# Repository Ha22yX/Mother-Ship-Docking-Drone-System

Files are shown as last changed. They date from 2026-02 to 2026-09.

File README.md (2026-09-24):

<div align="center">
  <h1>Mother-Ship Docking Drone System</h1>
  <p>My project exploring how GPS, UWB, and vision can work together for relative positioning and drone docking.</p>

  <p>
    <a href="README.zh-CN.md">Chinese</a>
    &middot;
    <a href="https://isef.rosebeg.com">Project Website</a>
    &middot;
    <a href="https://github.com/Ha22yX/UWB-Project">UWB Module</a>
    &middot;
    <a href="https://github.com/Ha22yX/OpenMV-AprilTag">Vision Module</a>
  </p>

  <p>
    
    
    
    
    
  </p>
</div>

<p align="center">
  Mother-Ship Docking Drone System overview: GPS, UWB, and vision for mother-frame relative positioning
</p>

I am building a system that would let a smaller drone approach and dock with a larger “mother” drone in the air. This repository records my hardware, code, and experiments as I work toward that goal.

**Current status:** I have completed the theoretical work and validation of the underlying principles. I have assembled the hardware and carried out preliminary flight tests, including a test with the two drones connected before takeoff. The complete autonomous approach and docking sequence is still unfinished.

## Why I started this project

I have thought drones were cool since I was a kid. I wanted to turn that interest into something I could design, build, and test myself, and getting two drones to meet and dock in the air gave me a problem I wanted to work on.

The question that drew me in was how to get an accurate relative position estimate over a wide range of distances. For the docking system I want to build, relying on a single sensing method makes it difficult to balance coverage, precision, and reliability.

GPS offers wide outdoor coverage, but ordinary GPS alone does not provide the precision I need for close docking. [RTK can improve GNSS accuracy](https://www.u-blox.com/en/technologies/rtk-real-time-kinematic) with correction data and suitable signal conditions. UWB and AprilTag vision can provide more precise local measurements for this task, but UWB needs the drone to stay within the anchors' useful range, and the camera needs a clear view of the marker at a usable distance.

That is why I want to combine these methods: satellite positioning for the wider approach, UWB for relative positioning as the drones get closer, and vision for the final alignment. My goal is to explore how sensor fusion can keep the relative position estimate useful across those stages, using drone docking as the application. It connects a positioning problem I want to solve with something I have enjoyed since childhood.

## What I am trying to build

I wanted to explore how one drone could find another and line up with it while both are moving. For docking, the smaller drone needs to know its position relative to the mother drone's frame, including how far it is from the docking point.

My design uses different sensors at different stages:

| Stage | Method | What I use it for |
| --- | --- | --- |
| Initial approach | GPS / RTK-GPS | Bring the drones into the same area. |
| Relative positioning | UWB anchors on the mother frame and a tag on the child drone | Calculate the child drone's position relative to the docking frame. |
| Close-range alignment | OpenMV camera and AprilTag markers | Estimate the remaining position and angle offset. |
| Connection | PX4 / MAVLink and an electromagnetic docking mechanism | Control the final approach and connect the two drones. |

The UWB part turns distances from several anchors into a local `x, y, z` estimate. The camera is intended to refine the alignment close to the docking point. The complete sequence still needs to be validated in flight.

## Building the hardware

I designed parts in SolidWorks and assembled physical prototypes for testing. The [CAD files](hardware/solidworks/) include the drone platform, docking frame, battery bay, GPS mounts, clamps, and electromagnet connectors.

The photo below shows the larger test setup with the mother frame and child drone.

<p align="center">
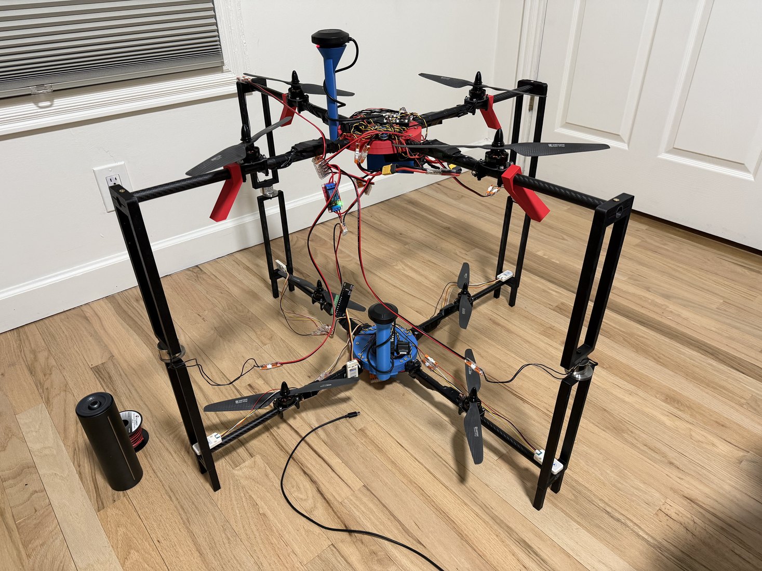
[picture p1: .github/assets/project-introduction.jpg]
Mother-frame docking structure and child drone in the assembled test setup
  
</p>

These two photos show my assembly work in more detail:

<table>
  <tr>
    <td align="center" width="50%">
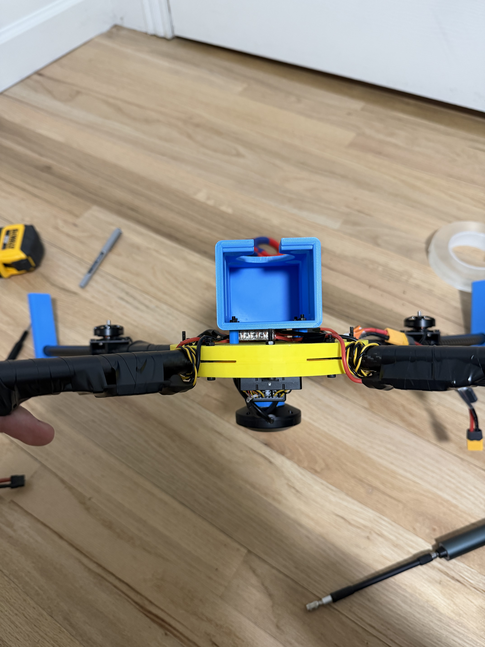
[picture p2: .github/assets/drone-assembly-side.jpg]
Side view of my drone assembly, showing the central frame, blue mount, wiring, and components underneath
      
    </td>
    <td align="center" width="50%">
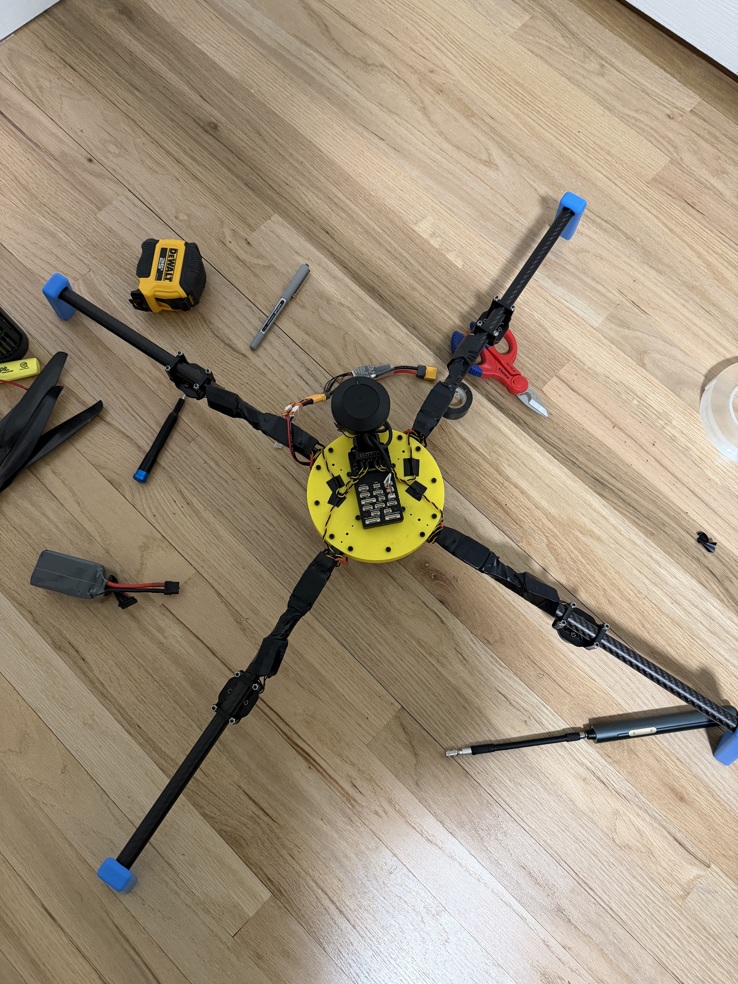
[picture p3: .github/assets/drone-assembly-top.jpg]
Top view of my drone assembly, showing the arms, motors, central plate, and electronics
      
    </td>
  </tr>
  <tr>
    <td align="center">Side view during assembly.</td>
    <td align="center">Top view of the frame and electronics during assembly.</td>
  </tr>
</table>

## Testing the two drones while connected

Before attempting docking between independently flying drones, I connected the two drones on the ground and tested them together. I wanted to check whether they could take off and fly safely in that connected configuration.

<p align="center">
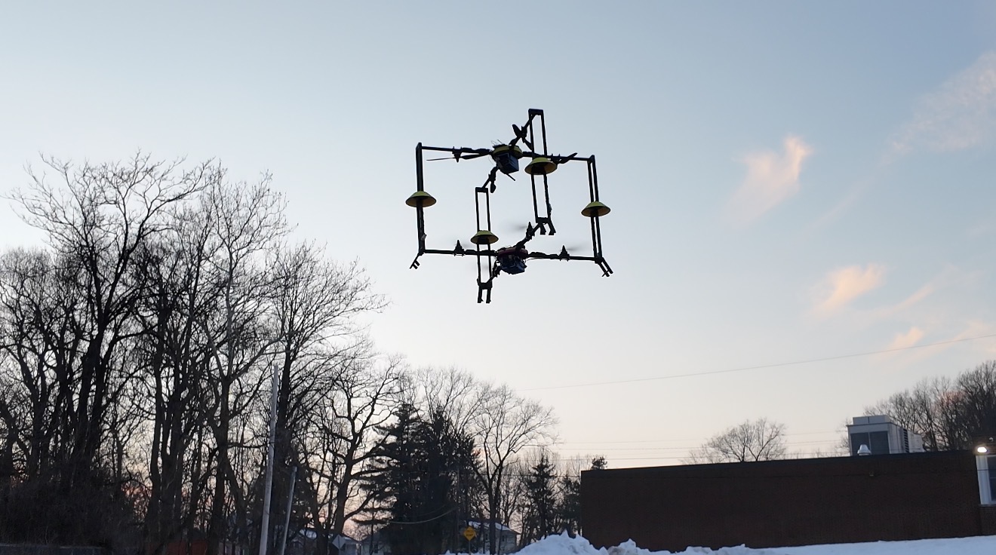
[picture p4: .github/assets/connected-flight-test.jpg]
The two drones airborne during a preliminary test with them already connected before takeoff
  
</p>

*The two drones during a flight test with them already connected before takeoff.*

This photo records a preliminary test of flying together. Autonomous approach, alignment, and connection in the air still need their own complete validation.

## Where I am now

| Part of the project | Progress |
| --- | --- |
| Theoretical design and validation of the underlying principles | Completed. |
| Hardware design and assembly | Physical prototypes built; CAD files and assembly photos included. |
| Flight with the drones already connected | Preliminary test carried out to investigate whether they could fly together safely. |
| Full flight and docking validation | Incomplete after multiple test attempts. |
| Autonomous mid-air docking | Not yet achieved. |

I have made multiple flight-test attempts, but they have not led to a completed autonomous docking demonstration. My current blocker is unstable altitude data in the existing open-source RTK-GPS software setup I have been using.

During stationary tests, **the reported GPS altitude kept fluctuating by approximately ±5 m even though the drone was not moving**. That makes it unsafe to continue the approach and docking experiments with the current setup. The theoretical work is complete, but the altitude issue and full flight validation still need to be resolved.

The repository includes a [GPS drift logger and plotter](gps_drift_test/GPS_Drift_Logger.py) for recording position data and inspecting altitude changes.

My next steps are to:

1. Resolve the altitude-data problem and check that the height readings are stable.
2. Validate the readings in controlled flight before resuming approach and docking tests.
3. Complete and document the full autonomous docking sequence.

## Code and tools

I use PX4/Pixhawk for flight control, ESP32-S3 boards for communication and sensor integration, and Python for debugging and analysis. I originally kept some of the whole-drone code in the UWB repository. It now lives here, alongside the rest of the docking project:

| Repository | What is in it |
| --- | --- |
| This repository | Mother/child ESP-NOW firmware, Pixhawk communication tests, UWB-to-flight-controller and OpenMV integration, debugging tools, GPS drift tools, CAD files, and project photos. |
| [UWB-Project](https://github.com/Ha22yX/UWB-Project) | The UWB module itself: ranging, filtering, position solving, anchor/tag firmware, wiring notes, and UWB visualization. |
| [OpenMV-AprilTag](https://github.com/Ha22yX/OpenMV-AprilTag) | AprilTag detection, position and orientation output, and PC visualization tools. |

The [firmware guide](firmware/README.md) explains the individual sketches. The [migration map](docs/repository-layout.md) records their old and new locations, including the older prototypes.

Some useful files in this repository:

```text
firmware/docking/               Mother and child ESP-NOW control sketches
firmware/pixhawk/               Pixhawk TELEM / MAVLink experiments
firmware/integration/           UWB position-to-Pixhawk follow-control experiment
firmware/openmv/                ESP32-side OpenMV UART and web-display experiments
tools/                         SiK radio debugging and AprilTag pose visualization
archive/old-main/               Earlier whole-drone prototypes and RTK forwarding script
docs/repository-layout.md       Repository responsibilities and migration map
Drone Control.py                 Early drone-control experiment
Router_Comm_Test.py              Router communication test
UDP_MAVLink_Comm_Test.py         Bidirectional MAVLink communication test
serial_px4_udp_router.py         Serial-to-UDP bridge for the flight controller
gps_drift_test/                  GPS recording and plotting tools
hardware/solidworks/             My SolidWorks source files
.github/assets/                 SVG overview and prototype, assembly, and flight-test photos
requirement.txt                 Python dependencies
```

## Running the experiments

Install Python and Git, then set up the repository:

```bash
git clone https://github.com/Ha22yX/Mother-Ship-Docking-Drone-System.git
cd Mother-Ship-Docking-Drone-System
pip install -r requirement.txt
```

The scripts are individual experiments. For example, `serial_px4_udp_router.py` connects a flight controller's serial link to UDP, and `UDP_MAVLink_Comm_Test.py` checks communication through that router. Their command-line options are available with:

```bash
python serial_px4_udp_router.py --help
python UDP_MAVLink_Comm_Test.py --help
```

For Arduino sketches, start with the [firmware guide](firmware/README.md). For the moved AprilTag 3D viewer, install its additional dependencies with `pip install -r tools/requirements.txt`; the [tools notes](docs/repository-layout.md#python-tools) explain which script to use.

Check ports, baud rates, network addresses, and PX4 settings against the actual hardware before running a test. These files are research code; flight use still requires bench checks, propeller-off tests, and failsafe setup. The CAD files also need dimensions, materials, and fasteners checked before fabrication.

## License

[MIT](LICENSE).

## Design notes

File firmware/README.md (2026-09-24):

# Drone firmware / 无人机固件

These are the ESP32-side sketches I use to explore communication, control, and sensor integration for my docking project. I originally put them in [UWB-Project](https://github.com/Ha22yX/UWB-Project), but they belong with the whole-drone system. Each folder is a separate experiment, not a component that is automatically built into one combined firmware.

这些是我为无人机对接项目写的 ESP32 端通信、控制和传感器接入草图。之前放在 UWB 仓库里，现在随整机项目维护。每个草图目录都是独立的实验，不能把它们全部一起烧录。完整自主空中对接仍未完成验证。

## Sketches / 草图用途

| Folder | Purpose / 用途 |
| --- | --- |
| [docking/UAVDocking_Mother_ESPNOW](docking/UAVDocking_Mother_ESPNOW/) | Mother-side telemetry, web controls, MAVLink, and ESP-NOW commands to the child. 母机端遥测、网页控制，以及与飞控和子机通信。 |
| [docking/UAVDocking_Child_ESPNOW](docking/UAVDocking_Child_ESPNOW/) | Child-side commands, telemetry, follow setpoints, and electromagnet control. 子机端指令、遥测、跟随目标和电磁铁控制。 |
| [pixhawk/pixhawk_telem1_sniffer](pixhawk/pixhawk_telem1_sniffer/) | Inspect the TELEM1 serial stream; includes a Python MAVLink decoder. 查看飞控串口数据，附电脑端解码脚本。 |
| [pixhawk/pixhawk_telem1_mavlink_parser](pixhawk/pixhawk_telem1_mavlink_parser/) | Parse MAVLink telemetry on the ESP32. 在 ESP32 上解析飞控遥测。 |
| [pixhawk/pixhawk_telem1_control_test](pixhawk/pixhawk_telem1_control_test/) | Experiment with commands sent to Pixhawk. 测试向飞控发送控制指令。 |
| [integration/uwb_follow_pixhawk](integration/uwb_follow_pixhawk/) | Solve UWB position and generate MAVLink velocity commands for a follow experiment. 将 UWB 位置解算接入飞控跟随控制。 |
| [openmv/openmv_uart_test](openmv/openmv_uart_test/) | Check the ESP32 serial connection to OpenMV. 测试 ESP32 与 OpenMV 的串口连接。 |
| [openmv/openmv_apriltag_web](openmv/openmv_apriltag_web/) | Receive AprilTag data on the ESP32 and display it on a web page. 在 ESP32 上接收 AprilTag 数据并通过网页显示。 |

The OpenMV folders above contain **ESP32 Arduino sketches**. The camera-side scripts remain in [OpenMV-AprilTag](https://github.com/Ha22yX/OpenMV-AprilTag). UWB-only ranging and position-solving experiments remain in [UWB-Project](https://github.com/Ha22yX/UWB-Project). Earlier whole-drone versions are in [archive/old-main](../archive/old-main/).

上面的 OpenMV 文件夹是 **ESP32 端 Arduino 程序**；摄像头端程序仍在视觉仓库。纯 UWB 测距与解算仍在 UWB 仓库，早期整机版本保存在归档目录。

## Opening a sketch / 打开草图

1. Install the ESP32 board package in Arduino IDE and select the board matching your hardware. These experiments target ESP32-S3 boards.
2. For sketches that include `MAVLink.h`, install the Arduino MAVLink library. ESP-NOW, Wi-Fi, web-server, and hardware-serial support come from the ESP32 core.
3. Open the `.ino` whose name matches its folder. Keep the companion `.h` and `.cpp` files in that same folder; both docking sketches depend on them.
4. Check the sketch's `config.h`, or the constants in its `.ino`, for the actual UART pins, baud rates, IDs, radio settings, and vehicle configuration before building it.

在 Arduino IDE 中选择实际使用的 ESP32-S3 开发板。需要 `MAVLink.h` 的草图还要安装 MAVLink 库。打开与目录同名的 `.ino`，保留同目录全部 `.h`、`.cpp` 文件，并按实际硬件检查引脚、波特率和通信参数。

The [main README](../README.md#where-i-am-now) records the current test status. Moving these files does not change the controller logic or complete the unfinished flight validation. See the [migration map](../docs/repository-layout.md) for their original locations and source revision.

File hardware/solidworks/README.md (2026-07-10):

# SolidWorks CAD Drawings

This folder contains the original SolidWorks drawings created during the Mother-Ship Docking Drone System hardware development.

Included files cover the drone platform, landing/docking frame, battery bay, GPS mounts, tube clamps, electromagnet connectors, motor/propeller reference parts, and related hardware pieces.

These files are provided as project source materials for documentation and future iteration. They are not manufacturing-ready release packages; check dimensions, materials, fasteners, and safety constraints before building from them.

## 中文说明

本文件夹保存 Mother-Ship Docking Drone System 硬件开发期间绘制的原始 SolidWorks 图纸。

内容包括无人机平台、起落/对接框架、电池仓、GPS 支架、管夹、电磁铁连接件、电机/螺旋桨参考件等硬件部件。

这些文件作为项目源材料和后续迭代参考提供，并不是可直接量产的制造发布包。实际加工前请重新检查尺寸、材料、紧固件和安全约束。

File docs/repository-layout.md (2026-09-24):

# Repository layout and migration / 仓库分工与迁移

I separated the UWB module from the code that connects it to the drone. The main repository now contains the mother/child controller sketches, Pixhawk communication experiments, sensor integration, and whole-system debugging tools. [UWB-Project](https://github.com/Ha22yX/UWB-Project) keeps the ranging, anchor/tag firmware, position solvers, UWB viewers, wiring notes, and module reference material.

我把 UWB 模块本身和无人机整机接入程序分开了：主仓库保存母机/子机控制、飞控通信、传感器接入和整机调试工具；UWB 仓库继续保存测距、锚点/标签固件、位置解算、UWB 可视化及模块资料。

## Migration map / 迁移对照表

Source: [UWB-Project at b06d21f](https://github.com/Ha22yX/UWB-Project/tree/b06d21fc8239b85ccc11ff70ba6198c6e617122c). The 55 migrated files were copied without changing their contents. Their earlier Git history remains in that repository. Sketch folder names and companion source files were kept together.

本次迁移保留了 55 个文件的原始内容。迁移前的历史仍可通过上面的 UWB 提交链接查看；Arduino 草图的目录名和配套源文件一起保留。

| Previous path in UWB-Project | Current path in this repository | Files |
| --- | --- | ---: |
| `firmware/docking/` | [firmware/docking/](../firmware/docking/) | 22 |
| `firmware/pixhawk/` | [firmware/pixhawk/](../firmware/pixhawk/) | 4 |
| `firmware/openmv/` | [firmware/openmv/](../firmware/openmv/) | 2 |
| `firmware/uwb/uwb_follow_pixhawk/` | [firmware/integration/uwb_follow_pixhawk/](../firmware/integration/uwb_follow_pixhawk/) | 1 |
| `archive/old-main/` | [archive/old-main/](../archive/old-main/) | 23 |
| `tools/debug/sik_debug.py` | [tools/debug/sik_debug.py](../tools/debug/sik_debug.py) | 1 |
| `tools/visualization/world_camera.py` | [tools/visualization/world_camera.py](../tools/visualization/world_camera.py) | 1 |
| `docs/reference/px4_mavlink_docs.md` | [docs/reference/px4_mavlink_docs.md](reference/px4_mavlink_docs.md) | 1 |

`uwb_follow_pixhawk` belongs here because it generates flight-controller commands from UWB positions. The standalone UWB solvers stay in the UWB repository. `world_camera.py` visualizes AprilTag pose data, so it moved with the OpenMV integration experiments.

`uwb_follow_pixhawk` 根据 UWB 位置生成飞控指令，所以归入整机接入实验；独立的 UWB 解算程序仍留在 UWB 仓库。`world_camera.py` 查看的是 AprilTag 位姿，因此随视觉接入实验一起迁入主仓库。

## Python tools

Run these from the main repository root after installing `pip install -r requirement.txt`:

| Script | Use / 用途 |
| --- | --- |
| [tools/debug/sik_debug.py](../tools/debug/sik_debug.py) | SiK telemetry-radio diagnostics; inspect arguments with `python tools/debug/sik_debug.py --help`. SiK 数传链路调试。 |
| [firmware/pixhawk/pixhawk_telem1_sniffer/pixhawk_mavlink_decode.py](../firmware/pixhawk/pixhawk_telem1_sniffer/pixhawk_mavlink_decode.py) | Decode a MAVLink serial stream using `pymavlink`. Check the configured serial port first. 解码飞控串口数据，运行前检查端口。 |
| [tools/visualization/world_camera.py](../tools/visualization/world_camera.py) | View AprilTag position and orientation in 3D. Install `pip install -r tools/requirements.txt` for NumPy, PyQtGraph, Qt, and OpenGL support; check the serial settings before launching. AprilTag 位姿三维查看器，需额外安装可视化依赖。 |
| [archive/old-main/rtk_base_forwarder/rtk_base_forwarder.py](../archive/old-main/rtk_base_forwarder/rtk_base_forwarder.py) | Earlier RTK correction forwarding experiment, retained with the old system code. 早期 RTK 修正数据转发实验，随旧版整机程序归档。 |

The [firmware guide](../firmware/README.md) covers the Arduino sketches. These are individual experiments; moving them into one repository does not mean they have been combined into a fully validated docking controller.

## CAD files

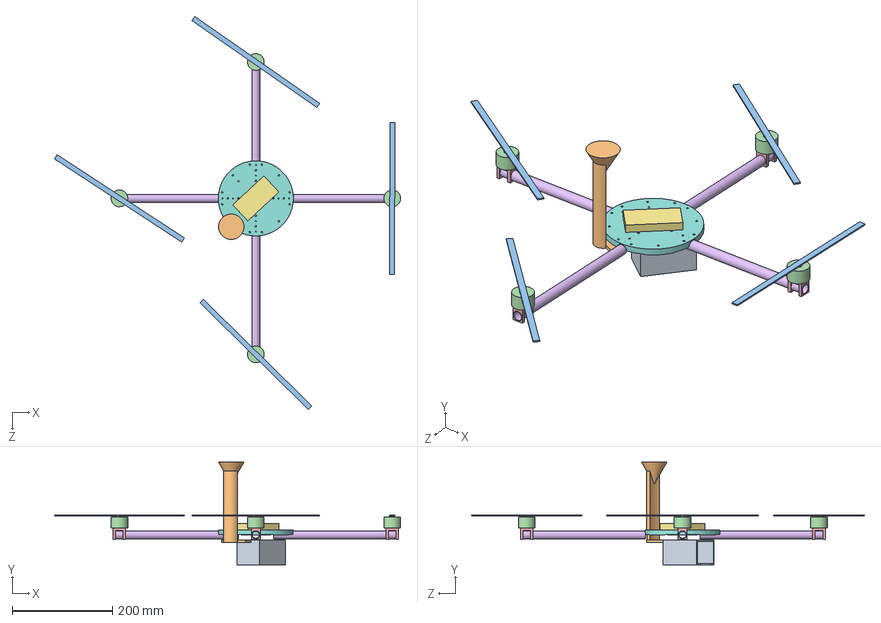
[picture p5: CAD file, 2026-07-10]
hardware/solidworks/无人机1.SLDASM
691.7 x 205.0 x 785.1 mm
平台
主控
碳纤维管 x 4
管夹 x 4
电机 x 4
螺旋桨 x 4
GPS支架
电池仓

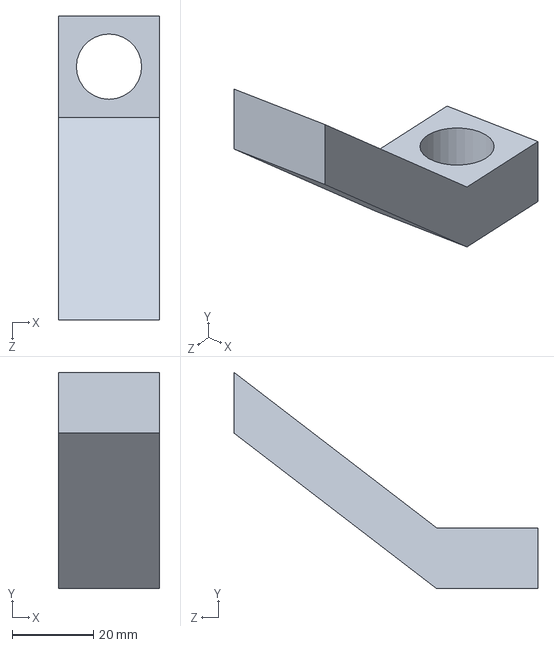
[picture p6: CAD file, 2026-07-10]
hardware/solidworks/起落支架.SLDPRT
25.0 x 53.4 x 75.0 mm

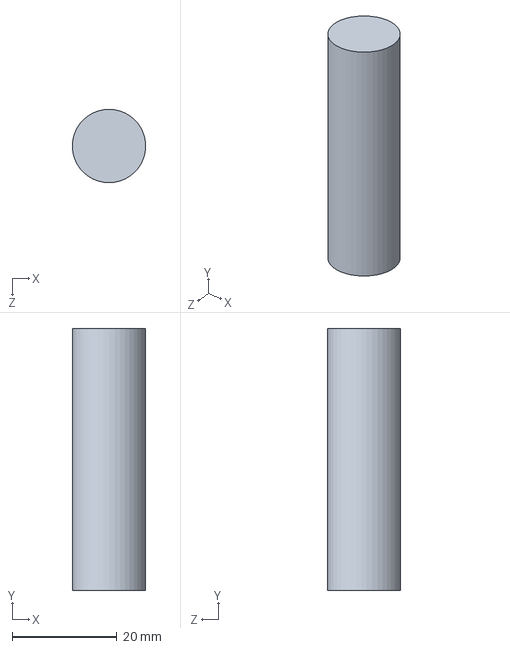
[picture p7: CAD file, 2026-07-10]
hardware/solidworks/管塞.SLDPRT
14.0 x 50.0 x 14.0 mm

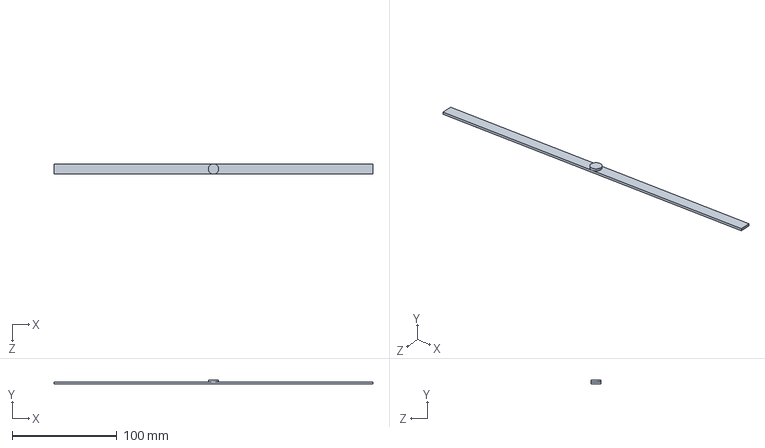
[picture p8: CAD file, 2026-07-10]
hardware/solidworks/螺旋桨.SLDPRT
304.0 x 4.00 x 10.0 mm

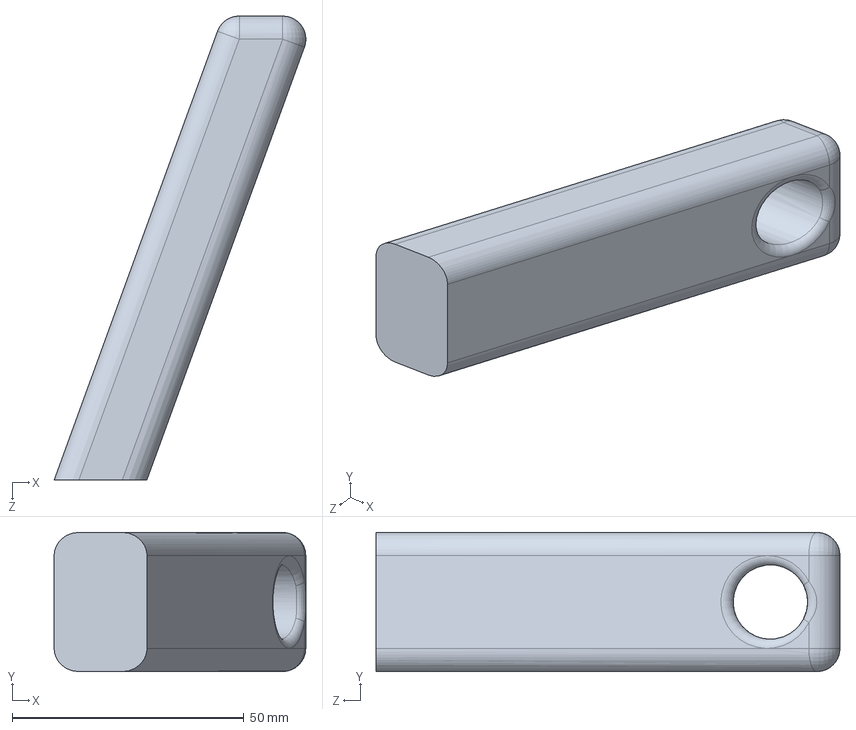
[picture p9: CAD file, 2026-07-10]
hardware/solidworks/起落架.SLDPRT
54.3 x 30.0 x 100.0 mm

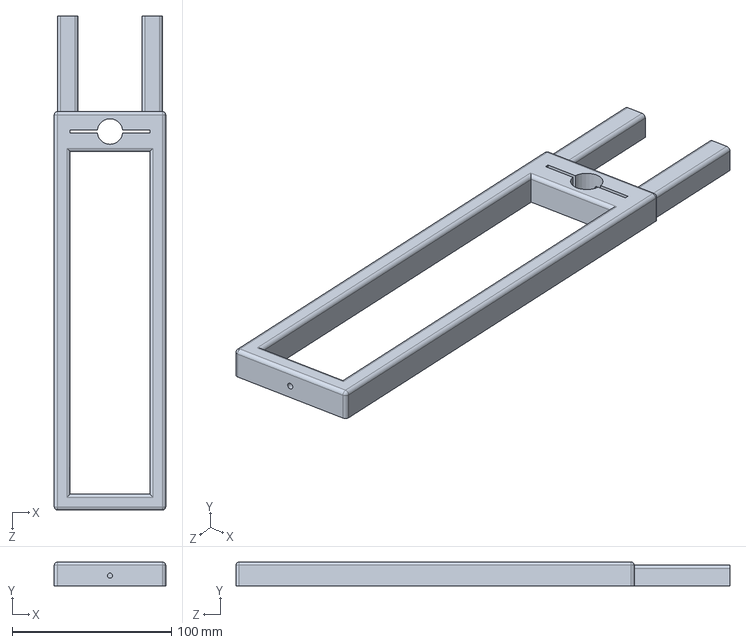
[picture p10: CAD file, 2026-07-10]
hardware/solidworks/磁铁吸附贴片连接支架.SLDPRT
70.0 x 15.0 x 310.0 mm

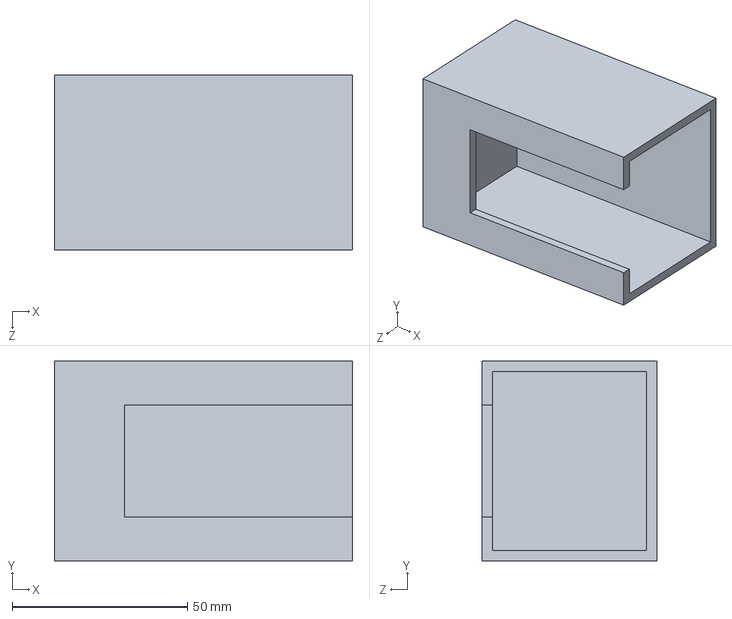
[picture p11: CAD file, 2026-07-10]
hardware/solidworks/电池仓.SLDPRT
85.0 x 57.0 x 50.0 mm

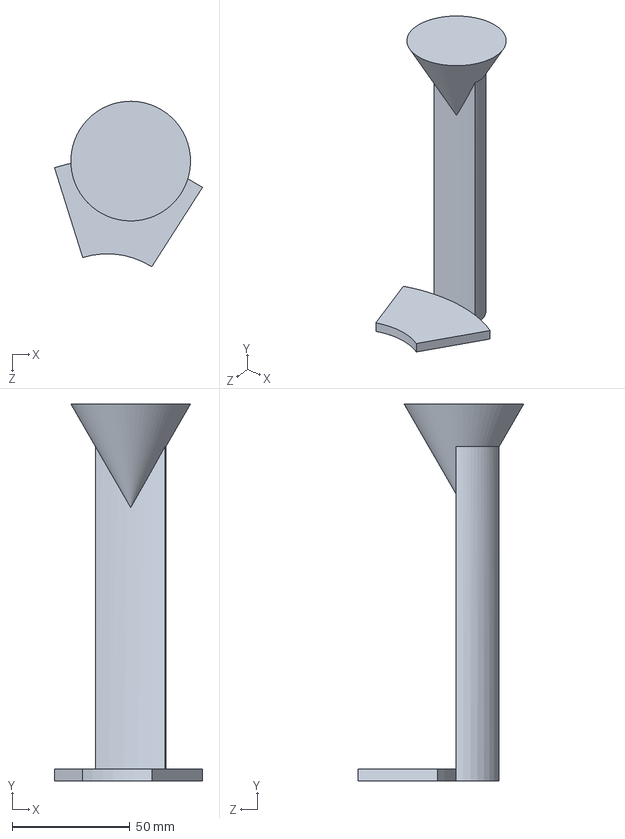
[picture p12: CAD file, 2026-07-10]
hardware/solidworks/GPS支架.SLDPRT
62.8 x 160.0 x 70.3 mm

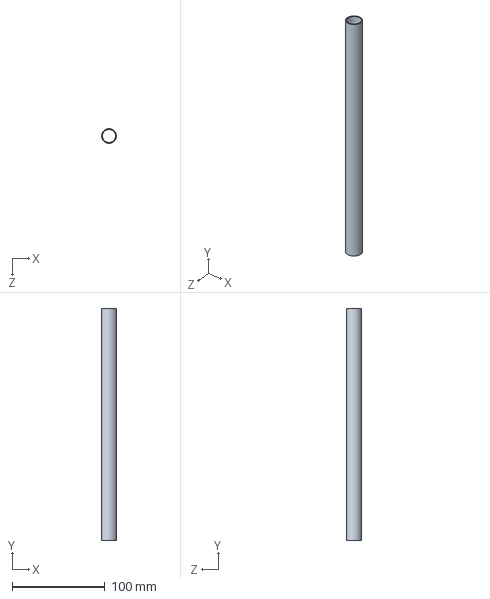
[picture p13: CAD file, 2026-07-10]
hardware/solidworks/碳纤维管.SLDPRT
16.0 x 250.0 x 16.0 mm

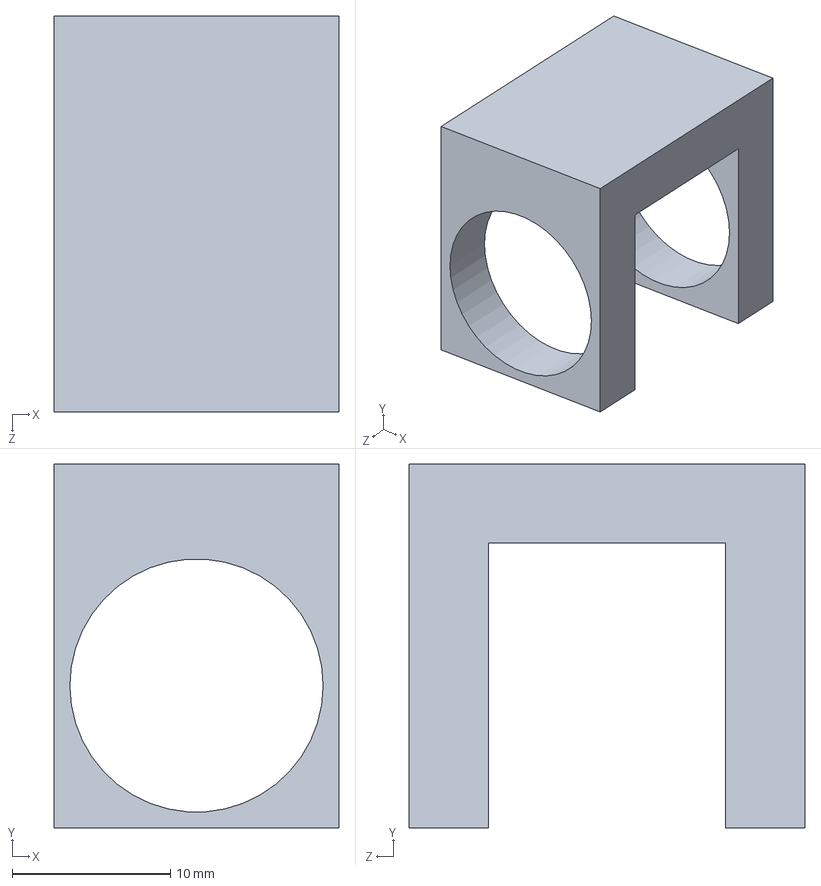
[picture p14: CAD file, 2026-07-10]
hardware/solidworks/管夹.SLDPRT
18.0 x 23.0 x 25.0 mm

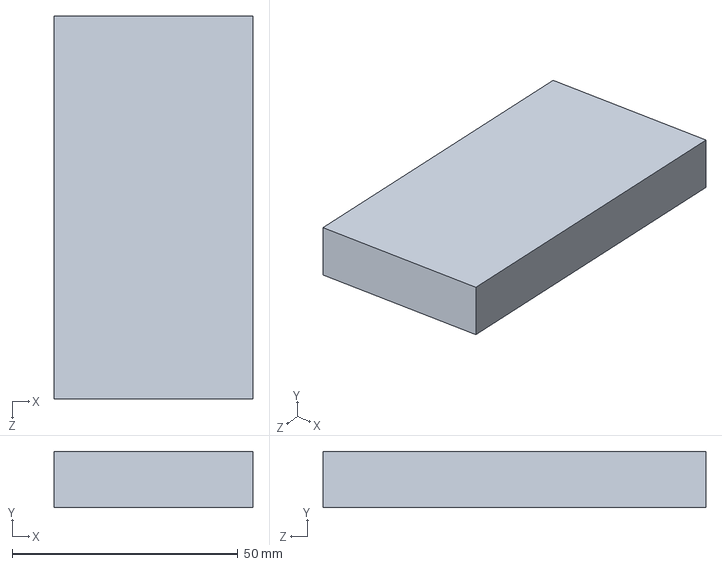
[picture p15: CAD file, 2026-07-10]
hardware/solidworks/主控.SLDPRT
44.0 x 12.4 x 84.8 mm

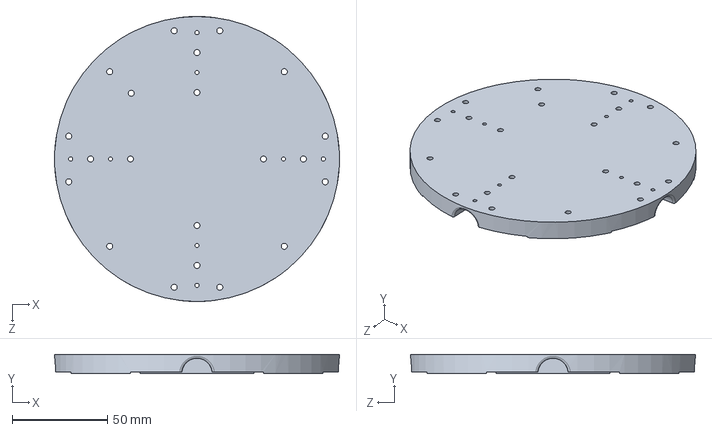
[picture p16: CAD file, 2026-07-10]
hardware/solidworks/平台.SLDPRT
150.0 x 10.0 x 150.0 mm

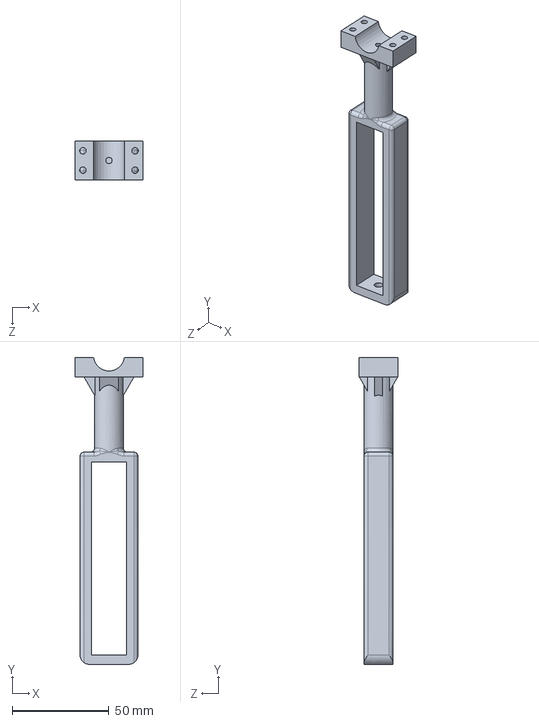
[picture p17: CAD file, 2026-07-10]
hardware/solidworks/电磁铁连接件简化版.SLDPRT
35.0 x 159.0 x 20.0 mm

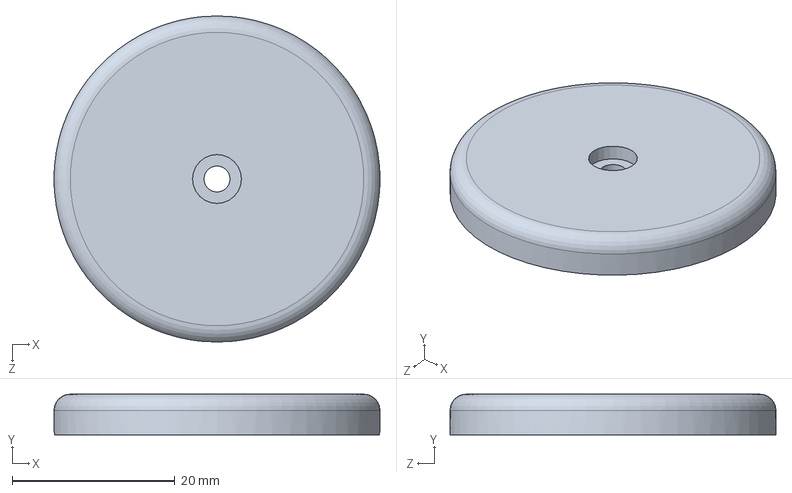
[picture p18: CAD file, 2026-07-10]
hardware/solidworks/磁铁吸附贴片.SLDPRT
40.0 x 5.00 x 40.0 mm

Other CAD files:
hardware/solidworks/电磁铁连接件.SLDPRT
hardware/solidworks/电池仓V2.SLDPRT
hardware/solidworks/贴片连接件简化版.SLDPRT
hardware/solidworks/电机.SLDPRT
hardware/solidworks/GPS支架V2.SLDPRT
hardware/solidworks/圆管夹片.SLDPRT

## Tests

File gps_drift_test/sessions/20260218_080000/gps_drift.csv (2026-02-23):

timestamp_s | lat_deg | lon_deg | alt_m | num_sats | hdop_or_eph | ekf_relative_alt_m
1771419600.0 | 30.0 | 120.0 | 100.0 | 12 | 1.15 | 0.0
1771419602.0 | 30.000001737 | 119.999998516 | 98.391295 | 12 | 1.208 | -0.246033
1771419604.0 | 29.999997886 | 120.000000526 | 97.482513 | 12 | 1.131 | -0.597699
1771419606.0 | 29.999999254 | 120.000001968 | 99.179163 | 12 | 1.214 | -0.584867
1771419608.0 | 29.999999301 | 120.000002363 | 97.87925 | 11 | 1.225 | -0.775997
1771419610.0 | 29.999998152 | 119.999998684 | 99.86522 | 11 | 1.165 | -0.597274
1771419612.0 | 29.999997921 | 119.99999674 | 98.318383 | 11 | 1.19 | -0.702391
1771419614.0 | 29.999999989 | 120.0000014 | 100.11064 | 11 | 1.223 | -0.535985
1771419616.0 | 30.000001183 | 120.000003513 | 99.58074 | 11 | 1.16 | -0.436002
1771419618.0 | 30.00000549 | 120.000005661 | 99.083252 | 11 | 1.186 | -0.442714
1771419620.0 | 30.000006054 | 120.000007319 | 100.389425 | 11 | 1.251 | -0.281219
1771419622.0 | 30.000003312 | 120.000013037 | 96.804546 | 12 | 1.158 | -0.74091
1771419624.0 | 30.000001629 | 120.000010535 | 97.58965 | 12 | 1.165 | -0.931892
1771419626.0 | 29.999998208 | 120.000007412 | 98.42619 | 12 | 1.169 | -0.956249
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

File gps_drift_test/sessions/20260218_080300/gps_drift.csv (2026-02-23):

timestamp_s | lat_deg | lon_deg | alt_m | num_sats | hdop_or_eph | ekf_relative_alt_m
1771419780.0 | 30.0 | 120.0 | 100.0 | 13 | 1.128 | 0.0
1771419782.0 | 30.000001475 | 119.999996513 | 102.225912 | 13 | 1.11 | 0.381765
1771419784.0 | 29.999999591 | 119.999994347 | 98.377711 | 13 | 1.045 | 0.004838
1771419786.0 | 30.000005537 | 119.999989633 | 101.391838 | 13 | 1.116 | 0.215429
1771419788.0 | 30.000004359 | 119.999991977 | 102.594718 | 13 | 1.079 | 0.550532
1771419790.0 | 30.000003347 | 119.999988557 | 100.516199 | 13 | 1.086 | 0.518219
1771419792.0 | 30.000003941 | 119.999987415 | 98.069186 | 14 | 1.052 | 0.0609
1771419794.0 | 30.000003997 | 119.999988306 | 98.525143 | 14 | 1.057 | -0.185663
1771419796.0 | 30.000004947 | 119.99998802 | 98.474382 | 14 | 1.003 | -0.378936
1771419798.0 | 30.000004502 | 119.999986472 | 97.227888 | 14 | 1.075 | -0.70575
1771419800.0 | 30.000004989 | 119.999990344 | 96.532293 | 14 | 1.074 | -1.137878
1771419802.0 | 30.000004899 | 119.999992302 | 100.25392 | 14 | 1.061 | -0.795901
1771419804.0 | 30.000008204 | 119.999990002 | 97.717201 | 14 | 0.946 | -0.971315
1771419806.0 | 30.000009182 | 119.999991549 | 98.889286 | 14 | 1.028 | -0.933299
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

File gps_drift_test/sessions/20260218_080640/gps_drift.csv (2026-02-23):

timestamp_s | lat_deg | lon_deg | alt_m | num_sats | hdop_or_eph | ekf_relative_alt_m
1771420000.0 | 30.0 | 120.0 | 100.0 | 14 | 1.075 | 0.0
1771420002.0 | 30.000000373 | 119.999994816 | 102.626376 | 14 | 1.036 | 0.454963
1771420004.0 | 30.000003929 | 119.999994358 | 99.285642 | 14 | 1.039 | 0.245635
1771420006.0 | 29.999999638 | 119.999995649 | 98.092092 | 13 | 1.127 | -0.116523
1771420008.0 | 29.999999212 | 119.999997122 | 99.930417 | 13 | 1.143 | -0.127612
1771420010.0 | 30.000000123 | 119.999997201 | 99.911451 | 13 | 1.076 | -0.117116
1771420012.0 | 29.999995965 | 119.999999626 | 100.673824 | 13 | 1.08 | 0.030647
1771420014.0 | 30.000000073 | 120.000004248 | 103.335092 | 13 | 1.09 | 0.568079
1771420016.0 | 30.000003443 | 120.000006749 | 101.625225 | 13 | 1.059 | 0.688448
1771420018.0 | 29.999999348 | 120.000013762 | 103.796669 | 13 | 1.066 | 1.073493
1771420020.0 | 29.999996374 | 120.000014177 | 102.089692 | 13 | 1.055 | 1.126045
1771420022.0 | 29.999999237 | 120.0000137 | 103.040394 | 13 | 1.042 | 1.355273
1771420024.0 | 29.999995813 | 120.000011542 | 101.121895 | 13 | 1.131 | 1.185111
1771420026.0 | 29.999994523 | 120.000008067 | 101.540125 | 13 | 1.091 | 1.166663
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

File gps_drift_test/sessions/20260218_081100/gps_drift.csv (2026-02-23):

timestamp_s | lat_deg | lon_deg | alt_m | num_sats | hdop_or_eph | ekf_relative_alt_m
1771420260.0 | 30.0 | 120.0 | 100.0 | 13 | 1.068 | 0.0
1771420262.0 | 30.000002727 | 120.000001839 | 103.356165 | 13 | 1.099 | 0.543823
1771420264.0 | 29.999999262 | 120.000003667 | 102.408428 | 13 | 1.071 | 0.777612
1771420266.0 | 29.999995977 | 120.000001754 | 101.033856 | 13 | 1.121 | 0.752708
1771420268.0 | 29.999993343 | 120.000001137 | 96.623849 | 13 | 1.104 | 0.021541
1771420270.0 | 29.999995775 | 120.000001923 | 99.538363 | 13 | 1.084 | -0.059079
1771420272.0 | 29.999996377 | 120.00000387 | 103.930064 | 12 | 1.097 | 0.572762
1771420274.0 | 29.999995009 | 120.000009975 | 104.793361 | 12 | 1.108 | 1.227615
1771420276.0 | 29.999996891 | 120.000015462 | 104.389936 | 12 | 1.183 | 1.660732
1771420278.0 | 29.999996434 | 120.000016912 | 100.518509 | 12 | 1.154 | 1.283468
1771420280.0 | 29.999993968 | 120.000013694 | 104.05659 | 13 | 1.121 | 1.629371
1771420282.0 | 29.999996998 | 120.000008583 | 104.598479 | 13 | 1.096 | 1.971507
1771420284.0 | 29.999999614 | 120.000012066 | 104.794758 | 13 | 1.127 | 2.223327
1771420286.0 | 29.999997867 | 120.000016716 | 104.705494 | 13 | 1.121 | 2.448758
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

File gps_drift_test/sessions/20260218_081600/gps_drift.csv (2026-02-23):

timestamp_s | lat_deg | lon_deg | alt_m | num_sats | hdop_or_eph | ekf_relative_alt_m
1771420560.0 | 30.0 | 120.0 | 100.0 | 16 | 0.964 | 0.0
1771420562.0 | 30.000000271 | 120.000001071 | 98.790117 | 16 | 0.997 | -0.149767
1771420564.0 | 30.000001567 | 120.000000073 | 102.114291 | 15 | 1.014 | 0.234121
1771420566.0 | 29.999996819 | 119.999999849 | 100.837867 | 14 | 1.097 | 0.330544
1771420568.0 | 29.999997264 | 119.999993982 | 103.488299 | 14 | 1.035 | 0.801316
1771420570.0 | 29.999996884 | 119.999994349 | 103.830296 | 14 | 1.071 | 1.217698
1771420572.0 | 29.999994847 | 119.999995199 | 103.702424 | 14 | 1.039 | 1.522436
1771420574.0 | 29.999995853 | 120.000003869 | 102.950386 | 14 | 1.067 | 1.600096
1771420576.0 | 29.99999843 | 120.000001512 | 103.804938 | 14 | 1.002 | 1.849004
1771420578.0 | 30.000000168 | 119.999994894 | 103.643248 | 14 | 1.051 | 1.954477
1771420580.0 | 30.000000019 | 119.999995827 | 97.691562 | 14 | 1.086 | 1.098534
1771420582.0 | 30.000004148 | 119.999992764 | 97.844578 | 14 | 1.026 | 0.47744
1771420584.0 | 30.000004416 | 119.999996966 | 100.043094 | 14 | 1.067 | 0.413848
1771420586.0 | 30.000008319 | 119.999995115 | 100.174288 | 13 | 1.133 | 0.368062
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

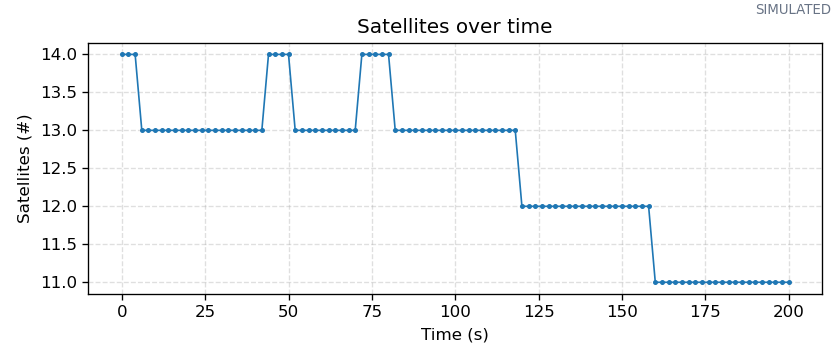
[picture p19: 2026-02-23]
gps_drift_test/sessions/20260218_080640/gps_satellites_over_time.png

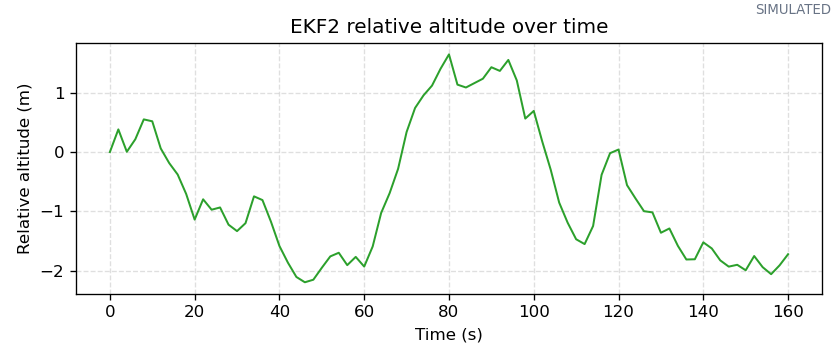
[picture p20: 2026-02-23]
gps_drift_test/sessions/20260218_080300/ekf_relative_alt_over_time.png

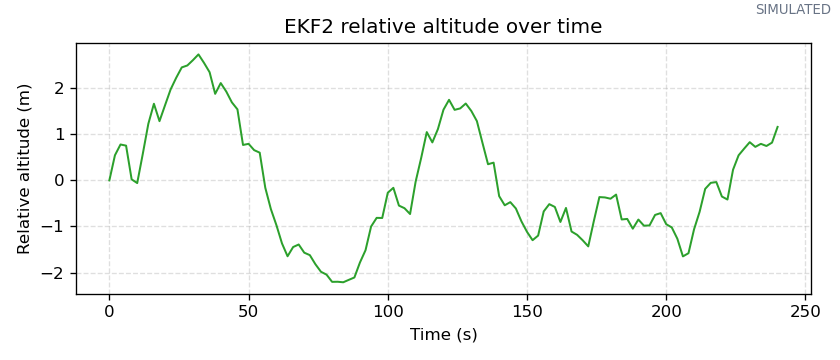
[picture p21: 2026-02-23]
gps_drift_test/sessions/20260218_081100/ekf_relative_alt_over_time.png

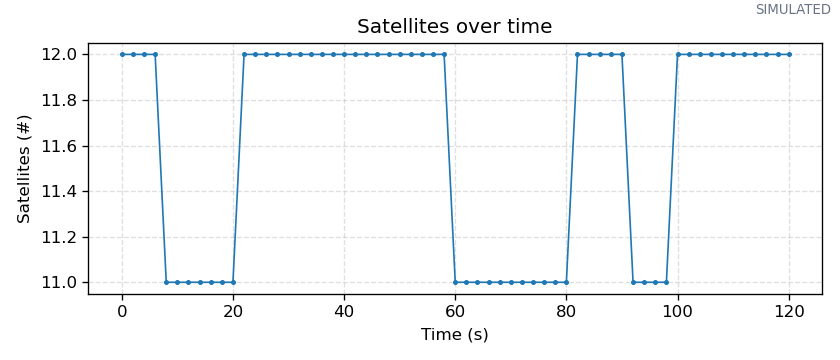
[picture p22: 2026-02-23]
gps_drift_test/sessions/20260218_080000/gps_satellites_over_time.png

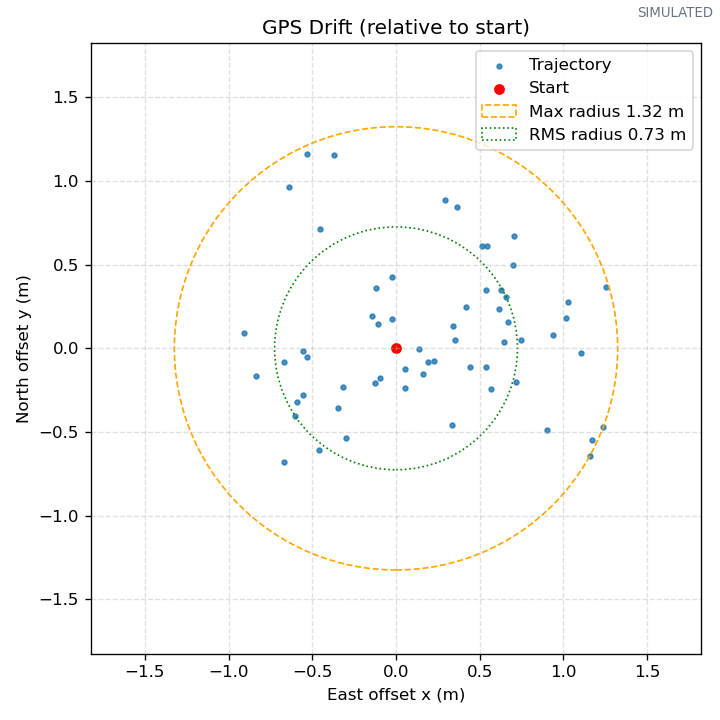
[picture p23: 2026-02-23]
gps_drift_test/sessions/20260218_080000/gps_drift_xy.png

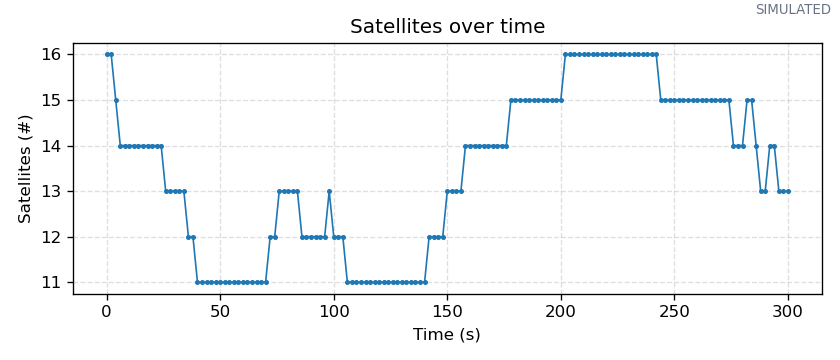
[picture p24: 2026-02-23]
gps_drift_test/sessions/20260218_081600/gps_satellites_over_time.png

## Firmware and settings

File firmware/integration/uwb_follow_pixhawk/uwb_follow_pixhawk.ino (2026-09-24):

#include <Arduino.h>
#include <MAVLink.h>

// --- UWB (Tag) wiring on ESP32-S3 ---
// GPIO4  -> UWB RX (Pin3)
// GPIO5  <- UWB TX (Pin4)
static const int UWB_RX = 5;
static const int UWB_TX = 4;
static const uint32_t UWB_BAUD = 115200;

// --- Pixhawk TELEM1 wiring ---
// Pin 2 (TX) -> ESP32-S3 IO10 (RX)
// Pin 3 (RX) -> ESP32-S3 IO11 (TX)
static const int FC_RX = 10;
static const int FC_TX = 11;
static const uint32_t FC_BAUD = 57600; // set to your TELEM1 baud

HardwareSerial UWB(1);
HardwareSerial FC(2);

// Anchor layout: square side 35.5 inches
static const float INCH_TO_M = 0.0254f;
static const float SIDE_M = 35.5f * INCH_TO_M;
static const float HALF = SIDE_M * 0.5f;

// Anchor coordinates (meters), midpoints of 4 edges
// Physical order clockwise: 1 -> 2 -> 3 -> 4
// Mapping to UWB IDs (an0..an3):
//   an0 = Anchor 1 (right midpoint)
//   an1 = Anchor 2 (bottom midpoint)
//   an2 = Anchor 3 (left midpoint)
//   an3 = Anchor 4 (top midpoint)
static const float AX[4] = {+HALF, 0.0f, -HALF, 0.0f};
static const float AY[4] = {0.0f, -HALF, 0.0f, +HALF};

// Filter
static const int FILTER_N = 3;
float distHist[4][FILTER_N] = {{0}};
int distCount[4] = {0, 0, 0, 0};
int distIndex[4] = {0, 0, 0, 0};
float distM[4] = {-1, -1, -1, -1};

// Control parameters
static float kp_xy = 0.6f;
static float kp_z = 0.6f;
static float max_v = 0.6f; // m/s
static float desired_z = 1.0f; // meters above anchor plane

static bool followEnabled = false;
static uint32_t lastUwbMs = 0;
static uint32_t lastSetpointMs = 0;

// MAVLink IDs
static const uint8_t SYS_ID = 255;
static const uint8_t COMP_ID = 190;
static const uint8_t TARGET_SYS = 1;
static const uint8_t TARGET_COMP = 1;

float medianN(float *v, int n) {
  float a[5];
  for (int i = 0; i < n; ++i) a[i] = v[i];
  for (int i = 0; i < n; ++i) {
    for (int j = i + 1; j < n; ++j) {
      if (a[j] < a[i]) {
        float t = a[i];
        a[i] = a[j];
        a[j] = t;
      }
    }
  }
  return a[n / 2];
}

float filterDistance(int id, float v) {
  distHist[id][distIndex[id]] = v;
  distIndex[id] = (distIndex[id] + 1) % FILTER_N;
  if (distCount[id] < FILTER_N) distCount[id]++;
  return medianN(distHist[id], distCount[id]);
}

void sendAT(const char *cmd) {
  UWB.print(cmd);
  UWB.print("\r\n");
  Serial.print("[CMD] ");
  Serial.println(cmd);
}

bool parseDistanceLine(const String &line, int &id, float &m) {
  if (!line.startsWith("an")) return false;
  int colon = line.indexOf(':');
  int mpos = line.indexOf('m');
  if (colon < 0 || mpos < 0) return false;
  id = line.substring(2, colon).toInt();
  m = line.substring(colon + 1, mpos).toFloat();
  if (id < 0 || id > 3) return false;
  return true;
}

bool solve2D(float &x, float &y) {
  if (distM[0] <= 0 || distM[1] <= 0 || distM[2] <= 0 || distM[3] <= 0)
    return false;

  float x0 = AX[0], y0 = AY[0], d0 = distM[0];
  float A11 = 0, A12 = 0, A22 = 0;
  float B1 = 0, B2 = 0;
  for (int i = 1; i < 4; ++i) {
    float xi = AX[i], yi = AY[i], di = distM[i];
    float ai = 2.0f * (xi - x0);
    float bi = 2.0f * (yi - y0);
    float ci = (xi * xi + yi * yi - di * di) -
               (x0 * x0 + y0 * y0 - d0 * d0);
    A11 += ai * ai;
    A12 += ai * bi;
    A22 += bi * bi;
    B1 += ai * ci;
    B2 += bi * ci;
  }
  float det = A11 * A22 - A12 * A12;
  if (fabs(det) < 1e-6f) return false;
  x = (B1 * A22 - B2 * A12) / det;
  y = (A11 * B2 - A12 * B1) / det;
  return true;
}

bool solve3DWithMirror(float &x, float &y, float &z) {
  if (!solve2D(x, y)) return false;
  float zsum = 0.0f;
  int zcount = 0;
  for (int i = 0; i < 4; ++i) {
    float dx = x - AX[i];
    float dy = y - AY[i];
    float z2 = distM[i] * distM[i] - dx * dx - dy * dy;
    if (z2 > 0) {
      zsum += sqrtf(z2);
      zcount++;
    }
  }
  if (zcount == 0) return false;
  z = zsum / zcount; // positive mirror
  return true;
}

void sendMavlink(const mavlink_message_t &msg) {
  uint8_t buf[MAVLINK_MAX_PACKET_LEN];
  uint16_t len = mavlink_msg_to_send_buffer(buf, &msg);
  FC.write(buf, len);
}

void sendHeartbeat() {
  mavlink_message_t msg;
  mavlink_msg_heartbeat_pack(
      SYS_ID, COMP_ID, &msg,
      MAV_TYPE_GCS, MAV_AUTOPILOT_INVALID,
      MAV_MODE_MANUAL_ARMED, 0, MAV_STATE_ACTIVE);
  sendMavlink(msg);
}

void sendArmDisarm(bool arm) {
  mavlink_message_t msg;
  mavlink_msg_command_long_pack(
      SYS_ID, COMP_ID, &msg,
      TARGET_SYS, TARGET_COMP,
      MAV_CMD_COMPONENT_ARM_DISARM,
      0,
      arm ? 1.0f : 0.0f,
      0, 0, 0, 0, 0, 0);
  sendMavlink(msg);
}

void sendSetModeOffboard() {
  mavlink_message_t msg;
  mavlink_msg_set_mode_pack(
      SYS_ID, COMP_ID, &msg,
      TARGET_SYS, MAV_MODE_FLAG_CUSTOM_MODE_ENABLED,
      PX4_CUSTOM_MAIN_MODE_OFFBOARD);
  sendMavlink(msg);
}

void sendVelocityBodyNED(float vx, float vy, float vz) {
  // Use velocity only in body frame
  uint16_t type_mask = (1 << 0) | (1 << 1) | (1 << 2) | // ignore position
                       (1 << 6) | (1 << 7) | (1 << 8) | // ignore accel
                       (1 << 9) | (1 << 10) | (1 << 11); // ignore yaw/yaw_rate
  mavlink_message_t msg;
  mavlink_msg_set_position_target_local_ned_pack(
      SYS_ID, COMP_ID, &msg,
      millis(), TARGET_SYS, TARGET_COMP,
      MAV_FRAME_BODY_NED, type_mask,
      0, 0, 0,
      vx, vy, vz,
      0, 0, 0,
      0, 0);
  sendMavlink(msg);
}

String readLineUwb() {
  static String line;
  while (UWB.available()) {
    char c = (char)UWB.read();
    if (c == '\r' || c == '\n') {
      if (line.length() > 0) {
        String out = line;
        line = "";
        return out;
      }
    } else if (c >= 32 && c <= 126) {
      line += c;
      if (line.length() > 120) {
        String out = line;
        line = "";
        return out;
      }
    }
  }
  return "";
}

String readLineUSB() {
  static String line;
  while (Serial.available()) {
    char c = (char)Serial.read();
    if (c == '\r' || c == '\n') {
      if (line.length() > 0) {
        String out = line;
        line = "";
        return out;
      }
    } else {
      line += c;
      if (line.length() > 80) {
        String out = line;
        line = "";
        return out;
      }
    }
  }
  return "";
}

void printHelp() {
  Serial.println("Commands:");
  Serial.println("  start        - arm + offboard + follow");
  Serial.println("  stop         - stop follow (zero velocity)");
  Serial.println("  kp <v>       - set kp_xy");
  Serial.println("  kz <v>       - set kp_z");
  Serial.println("  vmax <v>     - set max velocity");
  Serial.println("  z <v>        - set desired z (meters)");
}

void setup() {
  Serial.begin(115200);
  delay(300);
  UWB.begin(UWB_BAUD, SERIAL_8N1, UWB_RX, UWB_TX);
  FC.begin(FC_BAUD, SERIAL_8N1, FC_RX, FC_TX);

  Serial.println("ESP32 UWB follow -> Pixhawk (Offboard)");
  printHelp();

  sendAT("AT+anchor_tag=0");
  delay(100);
  sendAT("AT+interval=5");
  delay(100);
  sendAT("AT+switchdis=1");
}

void loop() {
  // Read UWB distances
  String line = readLineUwb();
  if (line.length() > 0) {
    int id;
    float m;
    if (parseDistanceLine(line, id, m)) {
      distM[id] = filterDistance(id, m);
      lastUwbMs = millis();
    }
  }

  // USB commands
  String cmd = readLineUSB();
  if (cmd.length() > 0) {
    cmd.trim();
    if (cmd == "start") {
      followEnabled = true;
      sendArmDisarm(true);
      sendSetModeOffboard();
      Serial.println("[CFG] follow start");
    } else if (cmd == "stop") {
      followEnabled = false;
      sendVelocityBodyNED(0, 0, 0);
      Serial.println("[CFG] follow stop");
    } else if (cmd.startsWith("kp ")) {
      kp_xy = cmd.substring(3).toFloat();
      Serial.print("[CFG] kp=");
      Serial.println(kp_xy);
    } else if (cmd.startsWith("kz ")) {
      kp_z = cmd.substring(3).toFloat();
      Serial.print("[CFG] kz=");
      Serial.println(kp_z);
    } else if (cmd.startsWith("vmax ")) {
      max_v = cmd.substring(5).toFloat();
      Serial.print("[CFG] vmax=");
      Serial.println(max_v);
    } else if (cmd.startsWith("z ")) {
      desired_z = cmd.substring(2).toFloat();
      Serial.print("[CFG] z=");
      Serial.println(desired_z);
    } else if (cmd == "help") {
      printHelp();
    }
  }

  // Send heartbeat at 1 Hz
  static uint32_t lastHb = 0;
  if (millis() - lastHb > 1000) {
    lastHb = millis();
    sendHeartbeat();
  }

  // Follow control at 10 Hz
  if (followEnabled && (millis() - lastSetpointMs) > 100) {
    lastSetpointMs = millis();

    float x, y, z;
    if (solve3DWithMirror(x, y, z)) {
      // Map to body NED: body right = +x, body forward = +y
      float vx = kp_xy * y;  // forward
      float vy = kp_xy * x;  // right
      float vz = -kp_z * (z - desired_z); // down

      if (vx > max_v) vx = max_v;
      if (vx < -max_v) vx = -max_v;
      if (vy > max_v) vy = max_v;
      if (vy < -max_v) vy = -max_v;
      if (vz > max_v) vz = max_v;
      if (vz < -max_v) vz = -max_v;

      // If data is stale, stop
      if (millis() - lastUwbMs > 1000) {
        vx = vy = vz = 0;
      }
      sendVelocityBodyNED(vx, vy, vz);
    } else {
      sendVelocityBodyNED(0, 0, 0);
    }
  }
}

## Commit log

2026-02-23 test: add GPS drift simulation reports
    Add five synthetic sessions dated 2026-02-18 at 0.5 Hz, lasting 120-300 seconds.
    Altitude drift remains within +/-5 m. Simulation provenance is retained.
    [gps_drift.csv]
2026-07-10 Expand README with prototype assets
    [GPS支架.SLDPRT, GPS支架V2.SLDPRT, 主控.SLDPRT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]
2026-10-27 docs: bring prototype and flight photos forward in READMEs
    Place hardware and connected-flight sections before the design and motivation. Move the overview diagram into the design section and keep English and Chinese layouts aligned.
